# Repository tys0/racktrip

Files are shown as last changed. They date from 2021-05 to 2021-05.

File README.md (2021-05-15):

# RackTrip
RackTrip is an open-source Eurorack module that sends audio and control voltage signals over the internet. Using Raspberry Pi Zero (W) and Pure Data, RackTrip virtually and remotely patches two modular synthesizers together at low-latency.

RackTrip prototype image

RackTrip's hardware has:
* 4 CV inputs
* 4 CV outputs
* 2 audio inputs
* 2 audio outputs
* USB-C port for wired internet connections through Ethernet over USB
* GUI Controls:
    * 1.3" OLED display (I2C)
    * Rotary encoder w/ push detent
    * Tactile push button

RackTrip's custom PCB is based on "Terminal Tedium," an open-source module for audio I/O, gate I/O, and CV input to Raspberry Pi. RackTrip utilizes a modified version of Miller Puckette's "Quacktrip" Pd patch to send uncompressed audio and control rate signals between peers at low latency. Once two RackTrip modules are connected via Internet, inputs to one module are mirrored on the respective outputs of the other.

**Note:** some WIP software has not yet made it onto this repo. Build / software setup instructions to follow. Stay tuned!

## License
Software:  \
Hardware: [][cc-by-nc-sa]

RackTrip's Pure Data patches use a modified version of Miller Puckette's 
[Quacktrip](http://msp.ucsd.edu/tools/quacktrip/) Pure Data patch. RackTrip's software, including its Pure Data patches and C++ programs, are licensed under an MIT license.

RackTrip's hardware design is influenced by mxmxmx's terminal tedium Raspberry Pi module ([github](https://github.com/mxmxmx/terminal_tedium)) and ornament & crime module ([github](https://github.com/mxmxmx/O_C), [website](https://ornament-and-cri.me)). As a derivative work, RackTrip's hardware, including schematic and PCB files, are licensed under a [Creative Commons Attribution-NonCommercial-ShareAlike 4.0 International License][cc-by-nc-sa] (CC BY-NC-SA 4.0).

[][cc-by-nc-sa]

[cc-by-nc-sa]: http://creativecommons.org/licenses/by-nc-sa/4.0/
[cc-by-nc-sa-image]: https://licensebuttons.net/l/by-nc-sa/4.0/88x31.png
[cc-by-nc-sa-shield]: https://img.shields.io/badge/License-CC%20BY--NC--SA%204.0-lightgrey.svg

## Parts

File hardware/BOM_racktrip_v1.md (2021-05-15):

# BOM for RackTrip

Using [O&C BOM](https://ornament-and-cri.me/build-it/) and [Terminal Tedium BOM](https://github.com/mxmxmx/terminal_tedium/wiki) as reference(s).

## Capacitors 0603
note: use 25v or better

| value | # | note | mouser # |
| --- | ---: | --- | --- |
| 18p | 8x | 0603 / NP0/C0G | 80-C0603C180J5G |
| 20pF | 2x | 0805 / NP0/C0G | 80-C0805C200J5G (change to 0603 later) |
| 10n | 5x | 0603 / NP0/C0G | 80-C0603C103J3G |
| 100n | 16x | 0603 / MLCC | 80-C0603C104K3R7081 |
| 470n | 3x | 0603 / MLCC | 80-C0603C474K3R |
| 1uF | 1x | 0805 / MLCC | 80-C0805C105K3R |
| 10uF | 2x | 0805 / MLCC | 80-C0805C106K3P or 963-TMK212BBJ106KG-T |

## Resistors 0603
| value | # | note | mouser # |
| --- | ---: | --- | --- |
| 200R | 1x | | 603-RC0603FR-07200RL |
| 220R | 4x | non-ferrite bead | 603-RC0603FR-07220RL |
| 220R | 4x | ferrite bead; buffer btwn wm8731 and rpi | 81-BLM18BB221SN1D |
| 510R | 2x | | 603-RC0603FR-07510RL |
| 1k | 2x | | 603-RC0603FR-071KL |
| 4k7 | 2x | | 603-RC0603FR-074K7L |
| 5k6 | 2x | | 603-RC0603FR-075K6L |
| 10k | 4x | | 603-RC0603FR-0710KL |
| 11k8 | 1x | | 603-RC0603FR-0711K8L |
| 12k4 | 0x (or 4x) | | 603-RC0603FR-0712K4L |
| 24k9 | 8x (or 4x) | | 603-RC0603FR-0724K9L |
| 27k | 2x | | 603-RC0603FR-0727KL |
| 33k | 1x | | 603-RC0603FR-0733KL |
| 47k | 6x | | 603-RC0603FR-0747KL |
| 100k | 12x | | 603-AC0603DR-07100KL |

## Electrolytic Caps, SMD

| value | # | note | mouser # |
| --- | ---: | --- | --- |
| 10uF | 5x | 16V or better; diameter < 5.3mm | 647-UUQ1E100MCL1GB |
| 33uF | 2x | 25V or better; diameter < 8mm | 140-VE330M1HTR0607|

## ICs/semis/etc:

| what | # | desc | package | mouser # |
| --- | ---: | --- | --- | --- |
| WM8731 | 1x | stereo codec | TSSOP-28 | 238-WM8731SEDS/V |
| AD5592R | 1x | DAC/ADC for CV | TSSOP-16 | 584-AD5592RBRUZ |
| MCP6004 | 1x | CV input op-amp | SOIC-14 | 579-MCP6004T-I/SL |
| OPA4172 | 1x | CV output op-amp | SOIC-14 | 595-OPA4172IDR |
| OPA1678 | 2x | Audio I/O op-amp | SOIC-8 | 595-OPA1678IDR |
| ADP150 | 1x | 3v3 regulator | TSOT | 584-ADP150AUJZ-3.3R7 |
| SM5817PL-TP | 2x | diodes for power | SOD-123FL | 833-SM5817PL-TP |
| LM4040-10v | 1x | 10v for ?? | SOT-23 | 926-LM4040DIM3100NPB |
| LM4040-2v5 | 1x | 2v5 for 2V bias circuit (CV output) | SOT-23 | 998-LM4040CYM3-2.5TR or  522-LM4040C25FTA |
| 5V DC converter | 1x | R-785.0-0.5 (or 1.0) | t-h | 919-R-785.0-0.5 |

## Through-Hole Parts:
| what | # | ref | where | note |
| --- | ---: | --- | --- | --- |
| Mono jacks | 12x | Thonkiconn PJ398SM | Thonk | |
| Rotary encoder | 1x | PEC11R | Mouser # 652-PEC11R-4220F-S24  | |
| tactile switch | 1x | mecs 5ETH935 | mouser # 642-5GTH935 or [sos electronics](https://www.soselectronic.com/products/mec/5gth935-102165) | |
| 12.288 MHz Crystal | 1x | 20pF | Mouser # 559-FOXS128-20-LF | HC-49/S, low-profile |
| inductance, 10uH | 1x | - | mouser # 542-78F100-RC | - |
| electrolytic capacitor, 10uF | 2x | 2.5mm / 16V+ (for DC block / audio output) | mouser # 647-UFG1H100MDM |

## Etc
| what | # | ref | where |
| --- | ---: | --- | --- |
| Knurled / Hex Nuts for jacks | 12x | | Thonk |
| Washers for jacks | 12x | | Thonk |
| 1.3" OLED display | 1x | SH1106 or SSD1306 / 128x64 / 4 Pins or I2C | Amazon |
| Encoder Knobs | 1x | Small Encoder BLACK (D Shaft) Rogan | Thonk |
| Switch bezel or cap | 1x | | mouser # 642-1SS09-09.5 or 642-1US09 |
| 1x4 Socket for OLED | 1x | "2.54mm, low profile but not “machined” sockets with round holes for the pins" | Mouser # 517-929870-01-04-RA |
| raspberry GPIO socket, 2x20 | 1x | RM2.54, extra-tall female socket for RPI (†) | mouser # 485-2222 |
| 2x5 male pins for power socket | 1x | | mouser # 649-67996-410HLF |
| 1x2 female pin for 5V jumper | 1x | | mouser # 517-929870-01-02-RA  |

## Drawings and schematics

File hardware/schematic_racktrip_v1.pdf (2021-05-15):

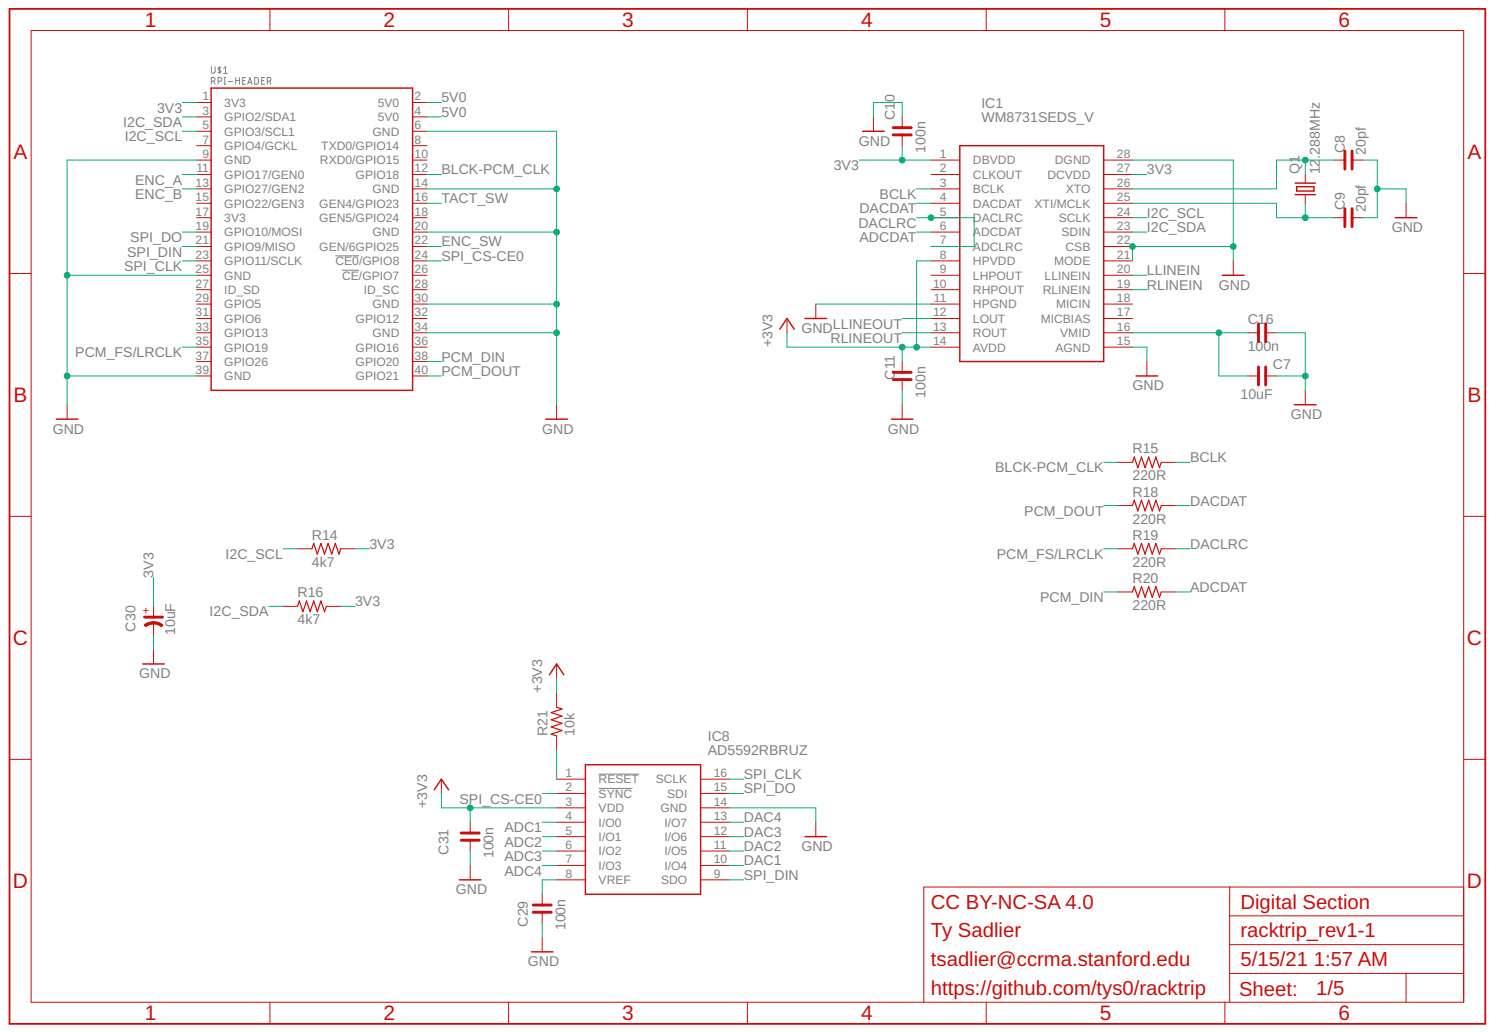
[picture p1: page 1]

Ty Sadlier
tsadlier@ccrma.stanford.edu
https://github.com/tys0/racktrip

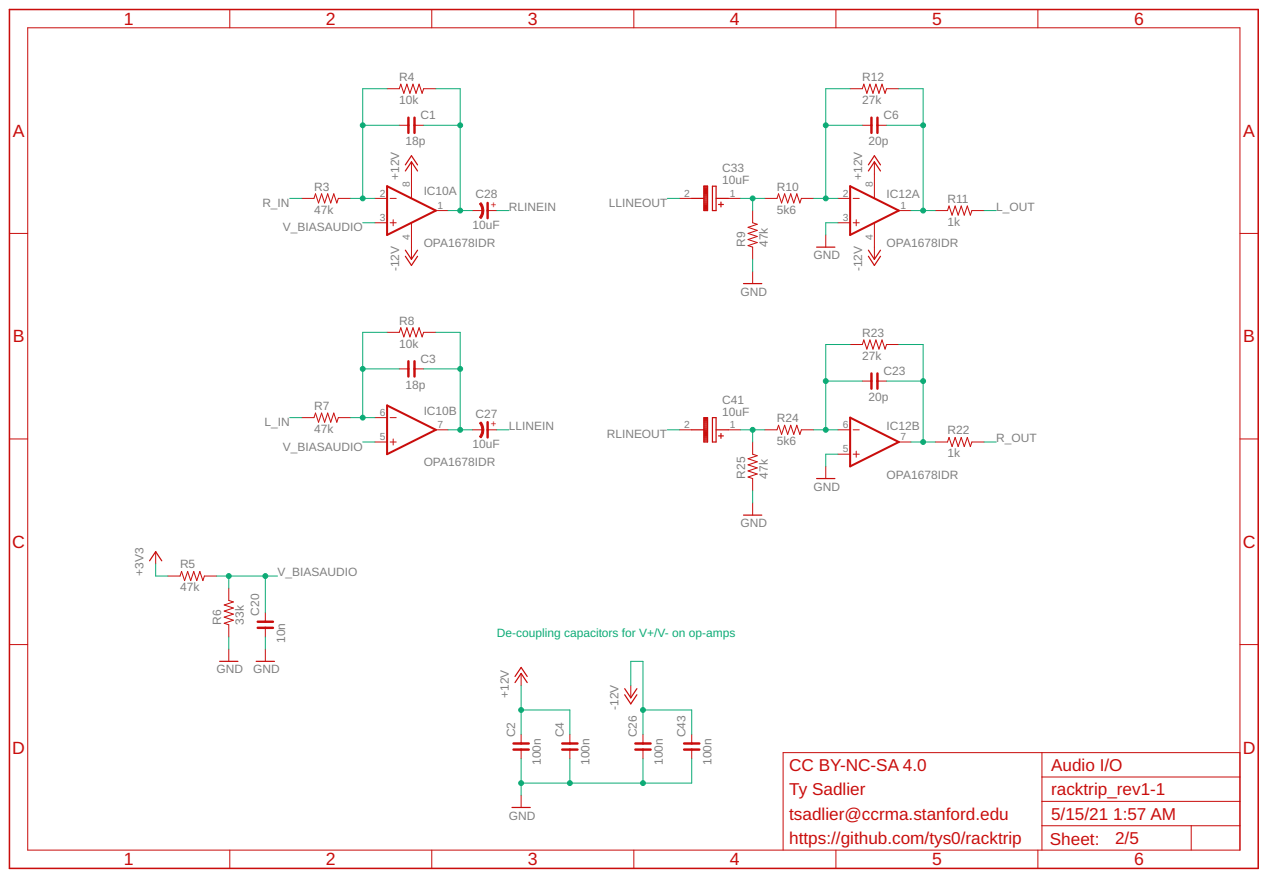
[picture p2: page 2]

De-coupling capacitors for V+/V- on op-amps

Ty Sadlier
tsadlier@ccrma.stanford.edu
https://github.com/tys0/racktrip

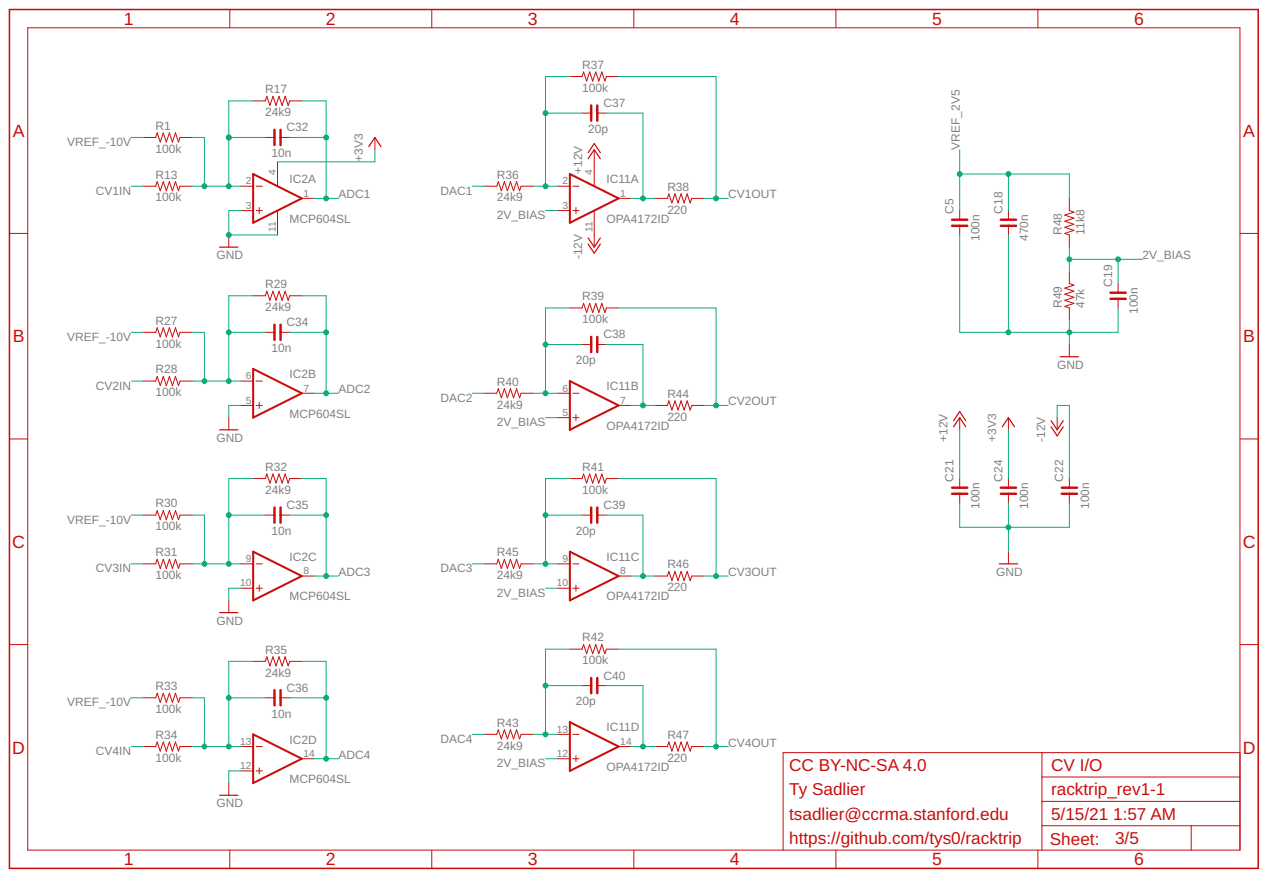
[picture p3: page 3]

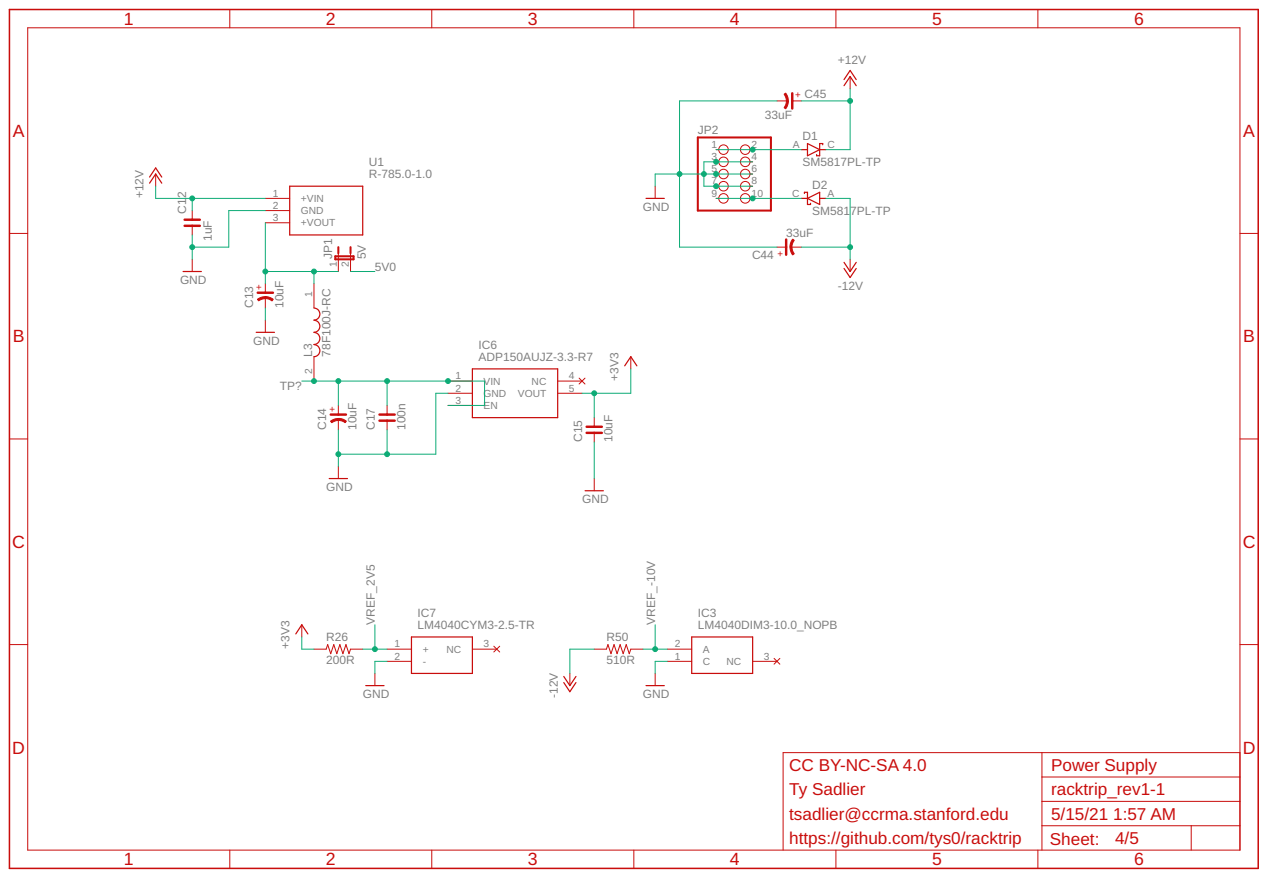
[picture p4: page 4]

+VOUT 3

Ty Sadlier
tsadlier@ccrma.stanford.edu
https://github.com/tys0/racktrip

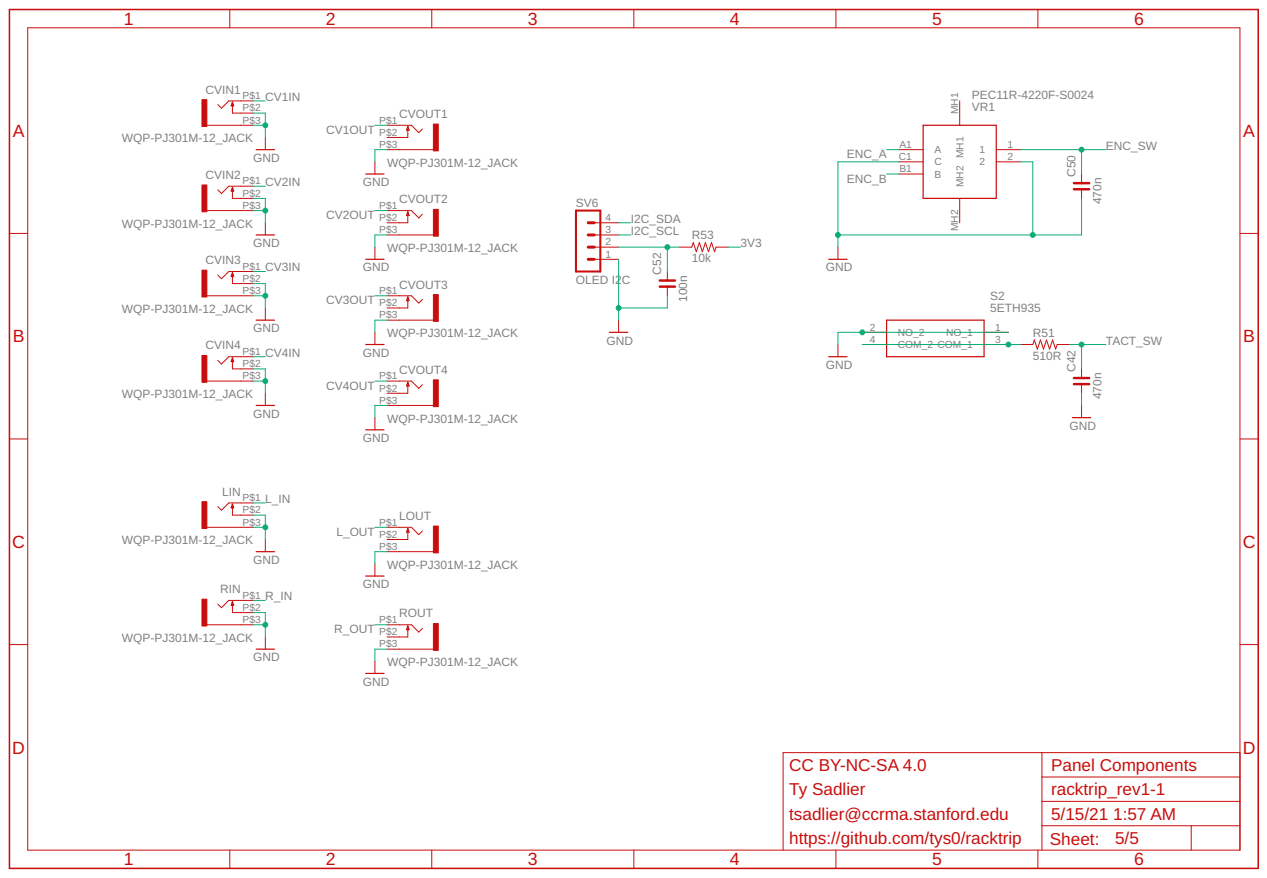
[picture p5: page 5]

Ty Sadlier
tsadlier@ccrma.stanford.edu
https://github.com/tys0/racktrip
